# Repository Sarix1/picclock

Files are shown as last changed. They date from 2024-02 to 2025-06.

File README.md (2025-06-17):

# PIC Digital Alarm Clock

A digital alarm clock using a PIC16F690 MCU

Created by [Sari Jokinen](https://github.com/sarix1) in December 2023 - February 2024

## Pictures

<table>
  <tr>
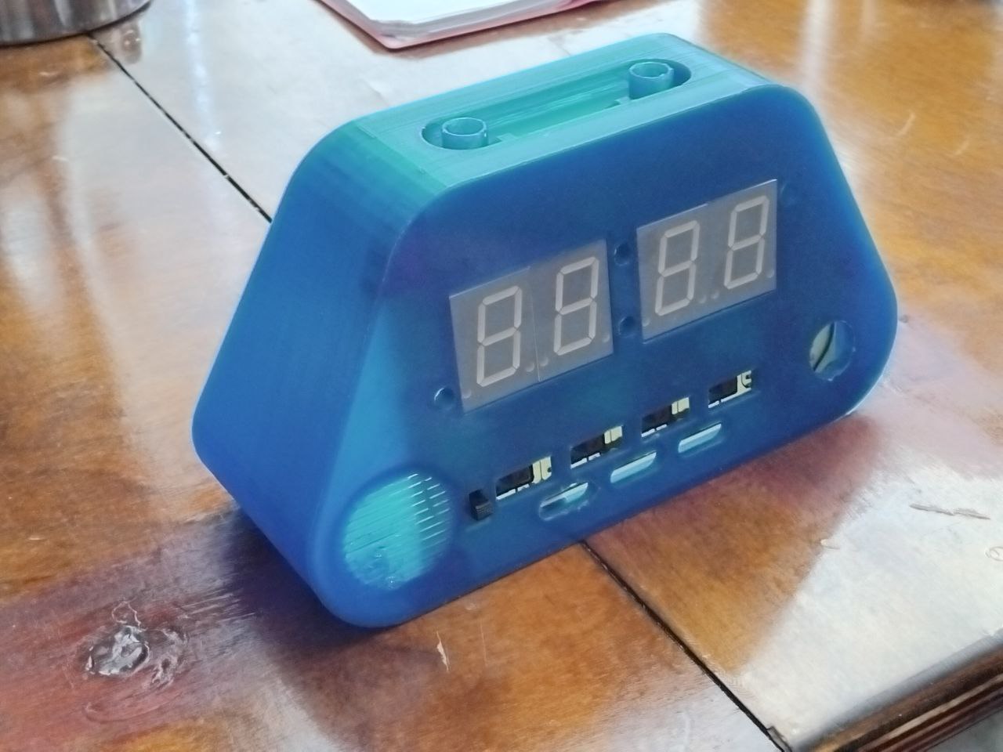
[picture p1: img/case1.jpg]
    <td></td>
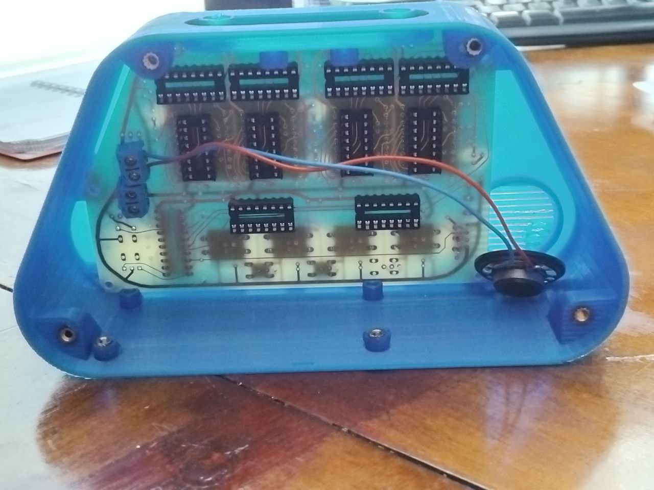
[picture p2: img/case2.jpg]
    <td></td>
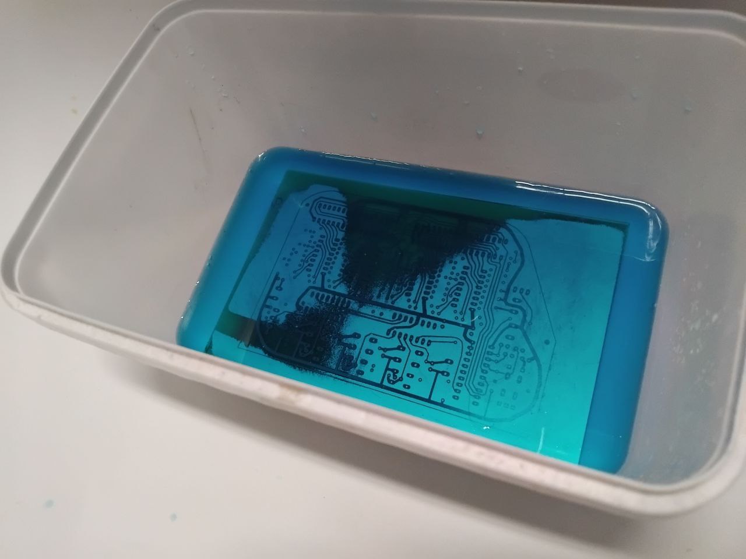
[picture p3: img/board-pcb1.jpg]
    <td></td>
  </tr>
  <tr>
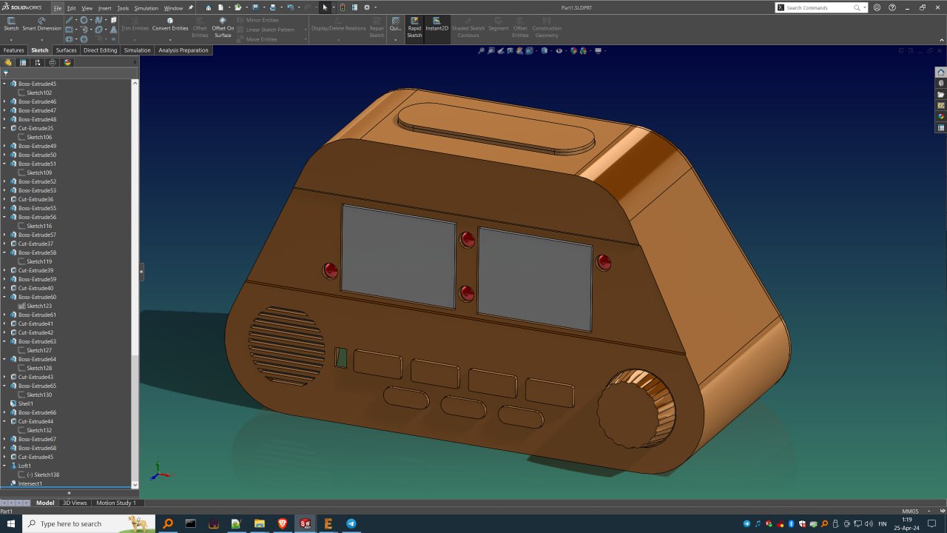
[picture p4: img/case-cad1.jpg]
    <td></td>
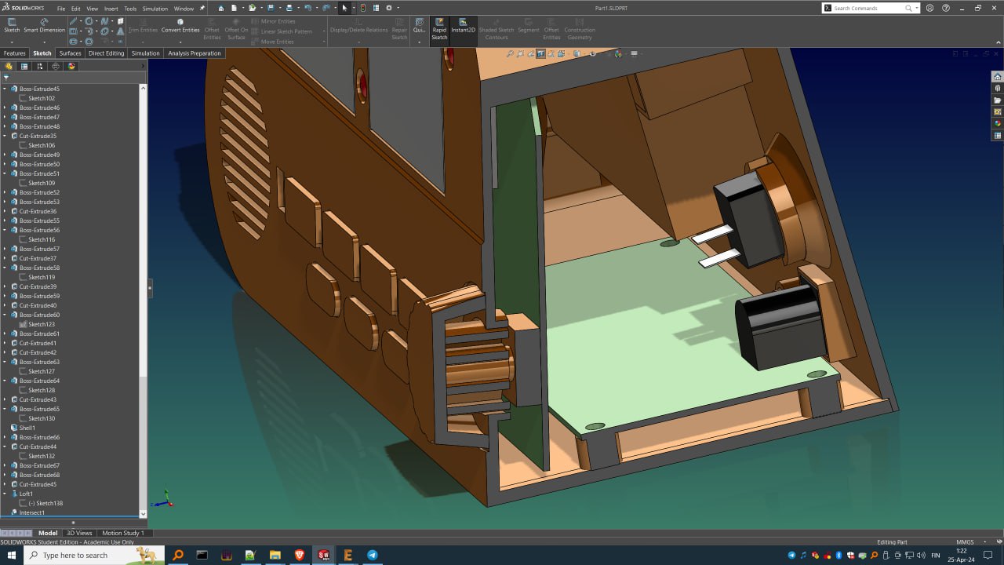
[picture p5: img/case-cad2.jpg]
    <td></td>
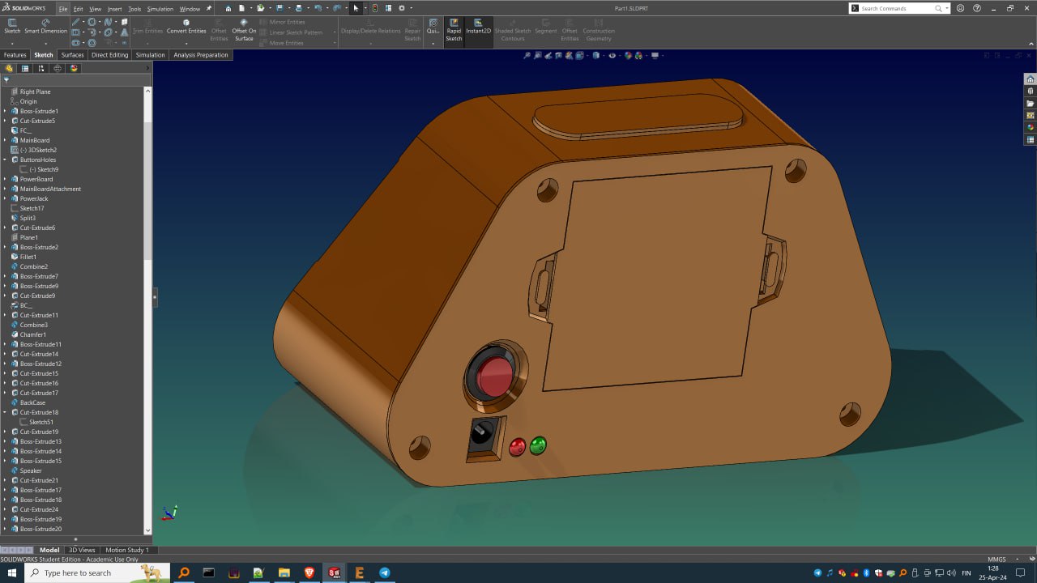
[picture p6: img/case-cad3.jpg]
    <td></td>
  </tr>
  <tr>
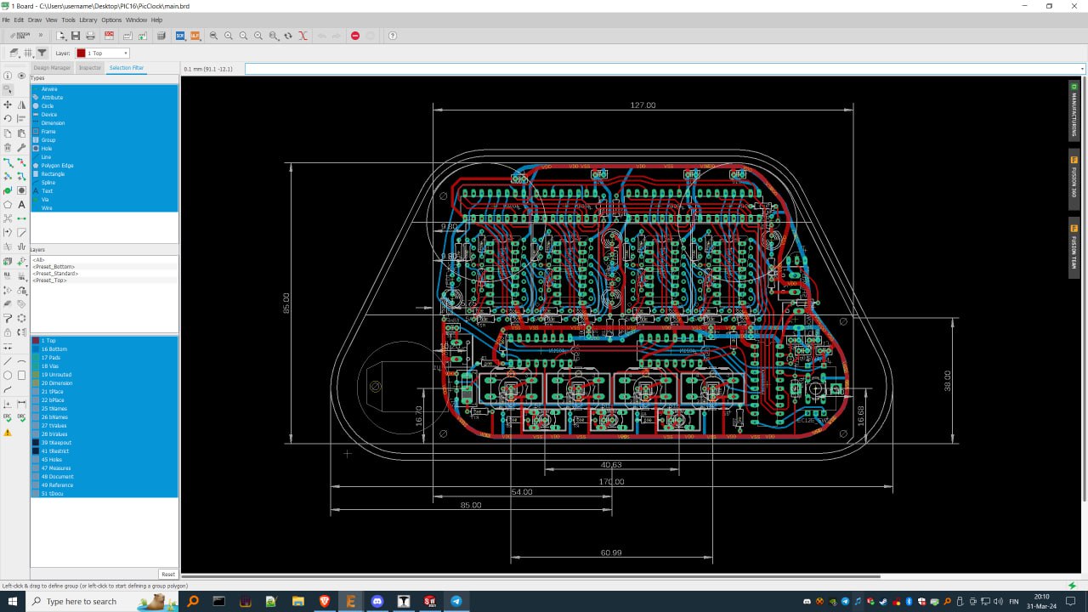
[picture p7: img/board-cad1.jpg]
    <td></td>
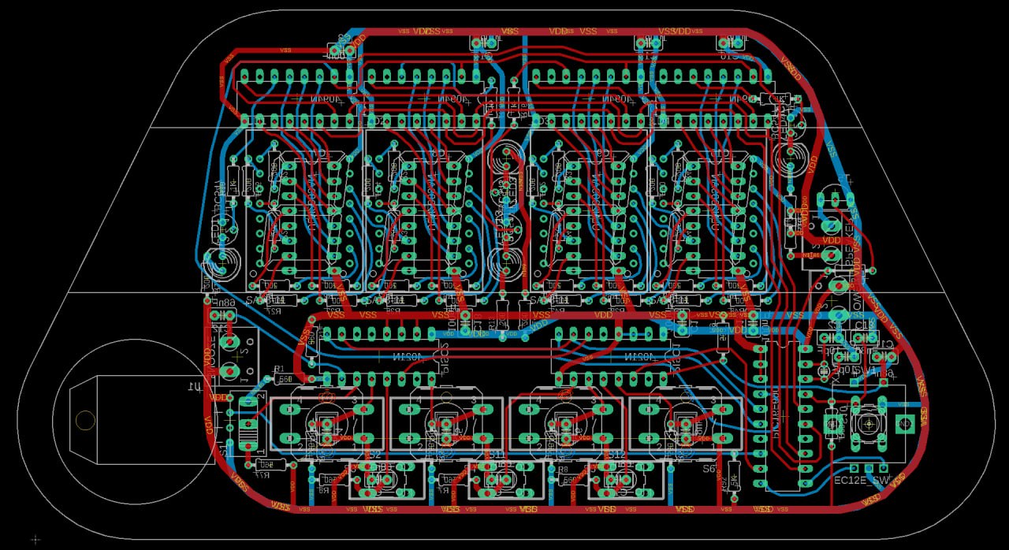
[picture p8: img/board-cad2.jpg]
    <td></td>
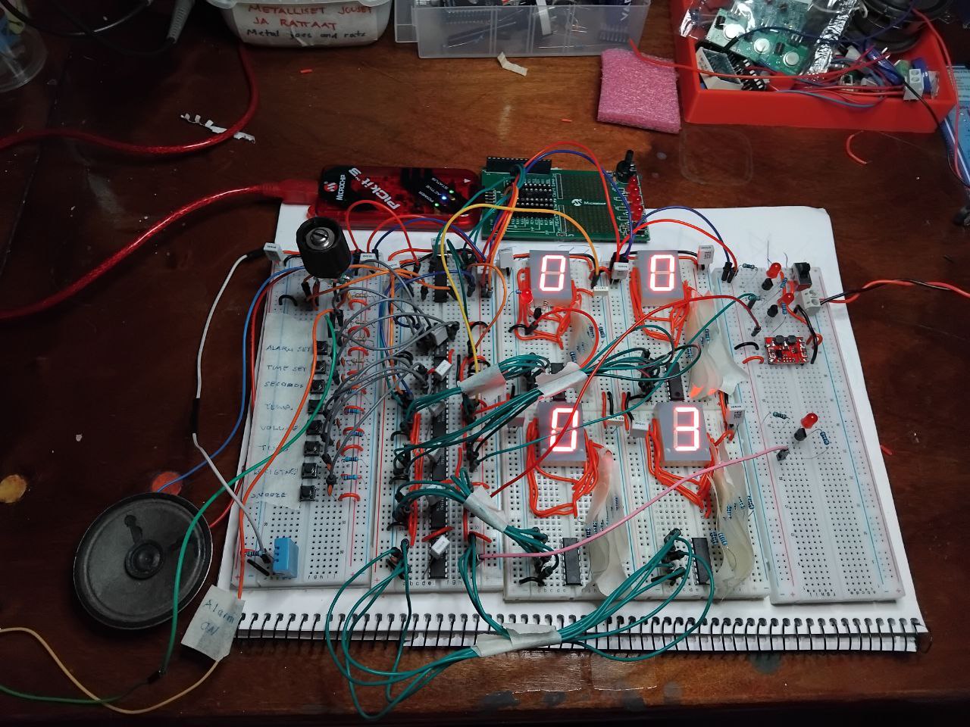
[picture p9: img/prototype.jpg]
    <td></td>
  </tr>
  <tr>
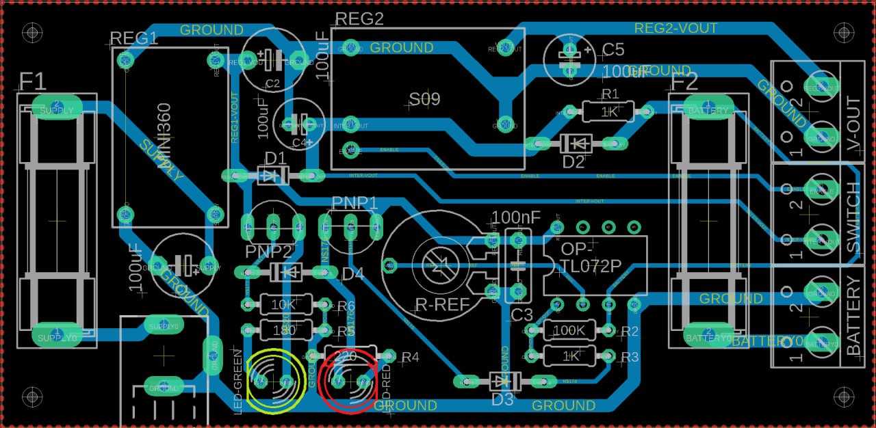
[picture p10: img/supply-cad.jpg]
    <td></td>
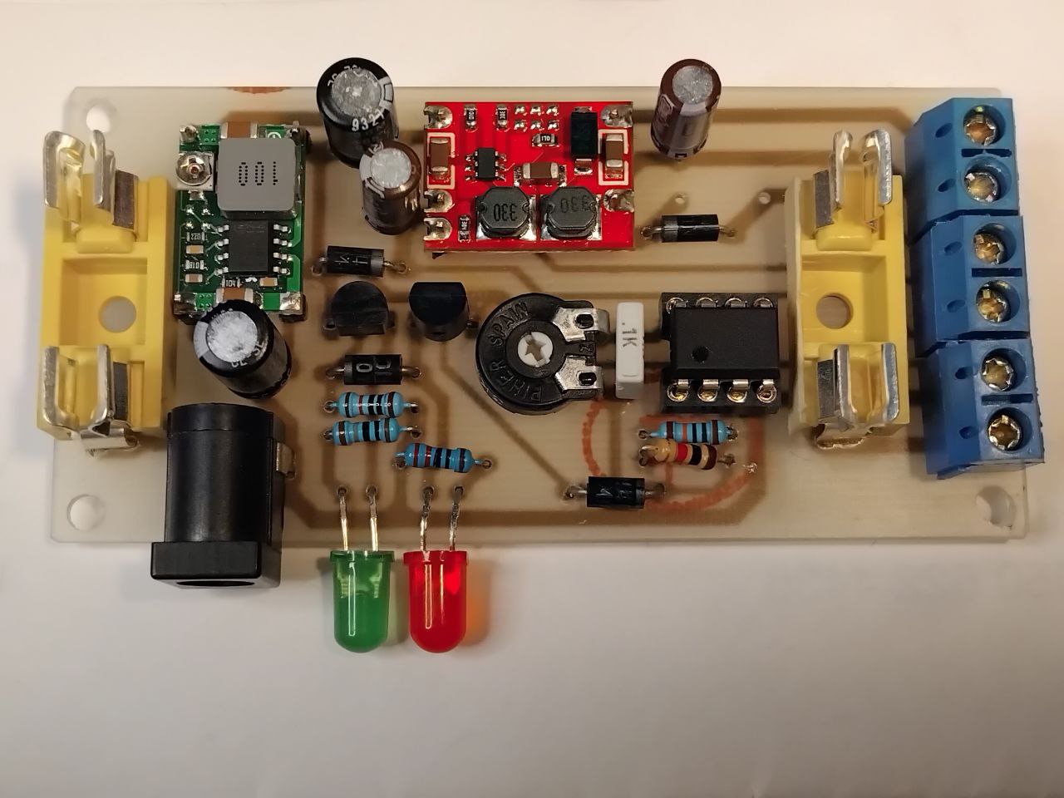
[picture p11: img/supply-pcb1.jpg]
    <td></td>
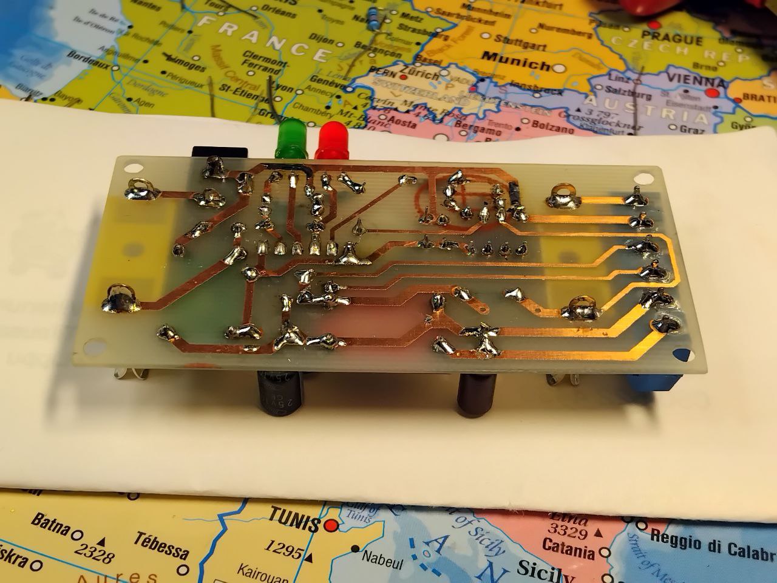
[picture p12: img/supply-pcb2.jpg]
    <td></td>
  </tr>
</table>

## Components

- PIC16F690 (20-pin, 8-bit MCU)
- 4 x 7-segment LED displays
- 10 x push-buttons
- Rotary encoder with push button
- DHT11 temperature/humidity sensor
- PWM-driven speaker on RC5/P1A
- 4 x SIPO shift registers (CD4094B) for display output
- 2 x PISO shift registers (CD4021B) for button input

## Pinout

### PIC16F690

```
                        _______     _______
                       |       \___/       |
                 +5V --|1 VDD        VSS 20|-- 0V
                       |                   |
              Xtal A ->|2 RA5        RA0 19|-- Unused
                       |   osc1            |
              Xtal B ->|3 RA4        RA1 18|-- Unused
                       |   osc2            |
               Reset ->|4 RA3        RA2 17|-> SIPO Output Enable
                       |   mclr       in   |
PWM / Speaker Signal <~|5 RC5        RC0 16|-> PISO Clock
                       |   p1a        out  |
          SIPO Latch <-|6 RC4        RC1 15|-> PISO Latch
                       |   out        out  |
              Unused --|7 RC3        RC2 14|-- Unused
                       |   p1c        p1d  |
           SIPO Data <-|8 RC6        RB4 13|<-> DHT11
                       |   out        an10 |
          SIPO Clock <-|9 RC7        RB5 12|<- PISO Data
                       |   out        in   |
      Rot. Encoder B ->|10 RB7       RB6 11|<- Rot. Encoder A
                       |    in        in   |
                       '-------------------'
                             PIC16F690
```

### Rotary Encoder
```
       ______    
  A <-|  __  |-> Button: Min/Hour
Gnd --| (__) |
  B <-|______|-- Gnd
```

### Parallel-In, Serial-Out Shift Registers
```
                     ____   ____
     Button Input ->|PI8 \_/ VDD|-- +5V
           Unused <-|Q6      PI7|<- Unused 
        PISO Data <-|Q8      PI6|<- BTN_SENSOR
     BTN_TIME_SET ->|PI4     PI5|<- BTN_SEC_SET
    BTN_ALARM_SET ->|PI3      Q7|-> Unused
      BTN_ENCODER ->|PI2     SER|<- CD4021B 2 Q8 <-.
TN_ALARM_TIMER_ON ->|PI1     CLK|<- PISO Clock     |
               0V --|VSS     LAT|<- PISO Latch     |
                    '-----------'                  |
                      CD4021B 1                    |
.--------------------------------------------------'
|                    ____   ____
|          Unused ->|PI8 \_/ VDD|-- +5V
|          Unused <-|Q6      PI7|<- Unused
'-- CD4021B 1 SER <-|Q8      PI6|<- Unused
       BTN_SNOOZE ->|PI4     PI5|<- Unused
   BTN_BRIGHT_SET ->|PI3      Q7|-> Unused
     BTN_TUNE_SET ->|PI2     SER|-> Unused
   BTN_VOLUME_SET ->|PI1     CLK|<- PISO Clock
               0V --|VSS     LAT|<- PISO Latch
                    '-----------'
                      CD4021B 2
```

### Serial-In, Parallel-Out Shift Registers
```
                     ____   ____
       SIPO Latch ->|LAT \_/ VDD|-- +5V
        SIPO Data ->|DAT      OE|<- LED Enable
       SIPO Clock ->|CLK      Q5|-> 7-Seg 1 E
        7-Seg 1 A <-|Q1       Q6|-> 7-Seg 1 F
        7-Seg 1 B <-|Q2       Q7|-> 7-Seg 1 G
        7-Seg 1 C <-|Q3       Q8|-> Unused
        7-Seg 1 D <-|Q4      Q'S|-> Unused
               0V --|VSS      QS|-> CD4094 2 DAT --.
                    '-----------'                  |
                      CD4094B 1                    |
.--------------------------------------------------'
|                    ____   ____
|      SIPO Latch ->|LAT \_/ VDD|-- +5V
'--> CD4094B 1 QS ->|DAT      OE|<- LED Enable
       SIPO Clock ->|CLK      Q5|-> 7-Seg 2 E
        7-Seg 2 A <-|Q1       Q6|-> 7-Seg 2 F
        7-Seg 2 B <-|Q2       Q7|-> 7-Seg 2 G
        7-Seg 2 C <-|Q3       Q8|-> Unused
        7-Seg 2 D <-|Q4      Q'S|-> Unused
               0V --|VSS      QS|-> CD4094 3 DAT --.
                    '-----------'                  |
                      CD4094B 2                    |
.--------------------------------------------------'
|                    ____   ____
|      SIPO Latch ->|LAT \_/ VDD|-- +5V
'--> CD4094B 2 QS ->|DAT      OE|<- LED Enable
       SIPO Clock ->|CLK      Q5|-> 7-Seg 3 E
        7-Seg 3 A <-|Q1       Q6|-> 7-Seg 3 F
        7-Seg 3 B <-|Q2       Q7|-> 7-Seg 3 G
        7-Seg 3 C <-|Q3       Q8|-> Unused
        7-Seg 3 D <-|Q4      Q'S|-> Unused
               0V --|VSS      QS|-> CD4094 4 DAT --.
                    '-----------'                  |
                      CD4094B 3                    |
.--------------------------------------------------'
|                    ____   ____
|      SIPO Latch ->|LAT \_/ VDD|-- +5V
'--> CD4094B 3 QS ->|DAT      OE|<- LED Enable
       SIPO Clock ->|CLK      Q5|-> 7-Seg 4 E
        7-Seg 4 A <-|Q1       Q6|-> 7-Seg 4 F
        7-Seg 4 B <-|Q2       Q7|-> 7-Seg 4 G
        7-Seg 4 C <-|Q3       Q8|-> Unused
        7-Seg 4 D <-|Q4      Q'S|-> Unused
               0V --|VSS      QS|-> Unused
                    '-----------'                  
                      CD4094B 4
```

## Hardware Layout Overview

```mermaid
graph TD
    subgraph "Buttons"
        BTN[10 Push Buttons]
    end
    
    subgraph "Direct Inputs"
        ENC[Rotary Encoder]
        DHT[DHT11 Sensor]
    end
    
    subgraph "Button Interface"
        PISO2[CD4021B #2]
        PISO1[CD4021B #1]
    end
    
    subgraph "Core"
        PIC[PIC16F690]
    end
    
    subgraph "Display Interface"
        SIPO1[CD4094B #1]
        SIPO2[CD4094B #2]
        SIPO3[CD4094B #3]
        SIPO4[CD4094B #4]
    end
    
    subgraph "Outputs"
        SEG[4x 7-Segment]
        SPK[Speaker]
    end
    
    BTN --> PISO2
    BTN --> PISO1
    PISO2 -->|Serial| PISO1
    PISO1 -->|Pin 12| PIC
    
    ENC -->|Pins 10,11| PIC
    DHT <-->|Pin 13| PIC
    
    PIC -->|Pin 8| SIPO1
    SIPO1 --> SIPO2
    SIPO2 --> SIPO3
    SIPO3 --> SIPO4
    
    SIPO1 --> SEG
    SIPO2 --> SEG
    SIPO3 --> SEG
    SIPO4 --> SEG
    
    PIC -->|Pin 5| SPK
```

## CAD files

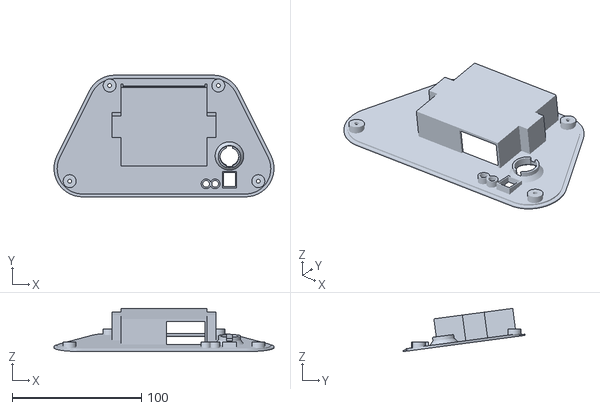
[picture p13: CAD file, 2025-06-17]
case/BackCase_v2.STL
170.0 x 94.0 x 33.4

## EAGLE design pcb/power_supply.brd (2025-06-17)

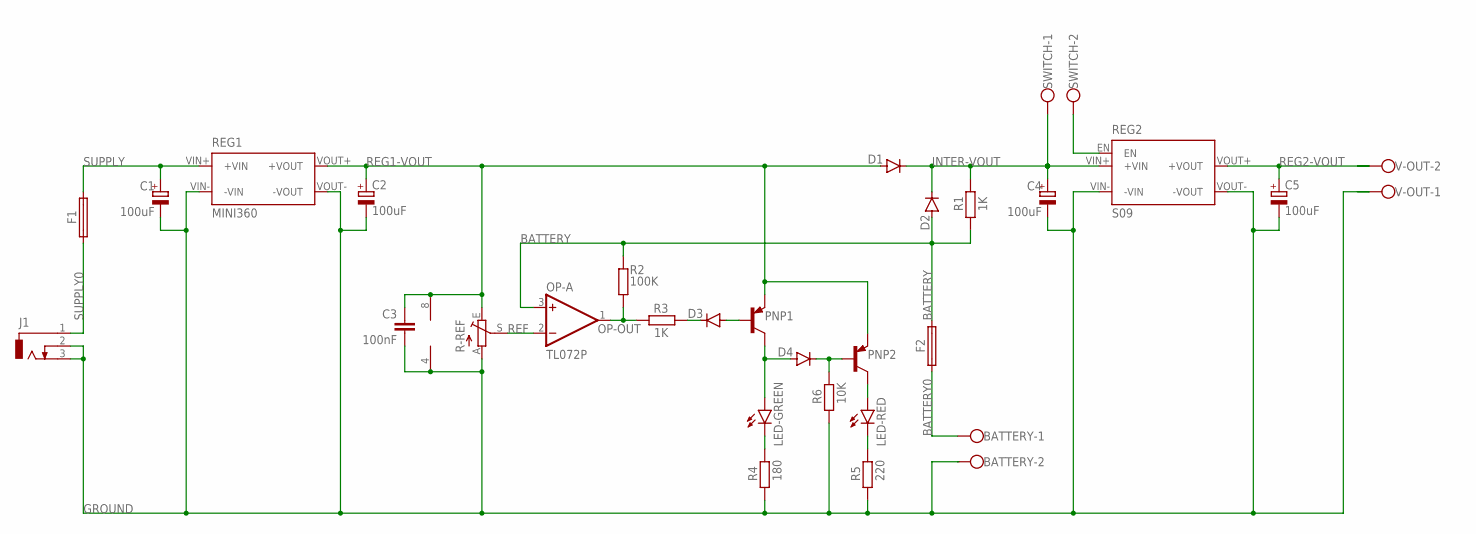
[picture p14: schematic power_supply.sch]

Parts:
BATTERY: W237-102
C1, C2: 100uF; E5-6
C3: 100nF; C5B2.5
C4, C5: 100uF; E2-5
D1, D2, D3, D4: BAS15; DO34-7
F1, F2: SH22,5
J1: DCJ0303
LED-GREEN: LED5MM
LED-RED: LED5MM
OP-: TL072P; DIL08
PNP1, PNP2: BC557A-PNP-TO92-EBC; TO92-EBC
R1, R3: 1K; 0204/7
R2: 100K; 0204/7
R4: 180; 0204/7
R5: 220; 0204/7
R6: 10K; 0204/7
R-REF: TRIM_EU-PT10; PT-10
REG1: MINI360; DC-DC-CONVERTER-MINI360
REG2: S09; DC-DC-CONVERTER-S09
SWITCH: W237-102
V-OUT: W237-102

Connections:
BATTERY: D2.A, F2.1, OP-.3 (+IN), R1.1, R2.2
BATTERY0: BATTERY.1, F2.2
ENABLE: REG2.EN, SWITCH.2
GROUND: BATTERY.2, C1.-, C2.-, C3.2, C4.-, C5.-, J1.2, J1.3, OP-.4 (V-), R4.1, R5.1, R6.1, R-REF.A, REG1.VIN- (-VIN), REG1.VOUT- (-VOUT), REG2.VIN- (-VIN), REG2.VOUT- (-VOUT), V-OUT.1
INTER-VOUT: C4.+, D1.C, D2.C, R1.2, REG2.VIN+ (+VIN), SWITCH.1
unnamed: LED-RED.A, PNP2.C
unnamed: D3.C, R3.1
unnamed: D3.A, PNP1.B
unnamed: D4.A, LED-GREEN.A, PNP1.C
unnamed: D4.C, PNP2.B, R6.2
unnamed: LED-RED.K (C), R5.2
unnamed: LED-GREEN.K (C), R4.2
OP-OUT: OP-.1 (OUT), R2.1, R3.2
REF: OP-.2 (-IN), R-REF.S
REG1-VOUT: C2.+, C3.1, D1.A, OP-.8 (V+), PNP1.E, PNP2.E, R-REF.E, REG1.VOUT+ (+VOUT)
REG2-VOUT: C5.+, REG2.VOUT+ (+VOUT), V-OUT.2
SUPPLY: C1.+, F1.2, REG1.VIN+ (+VIN)
SUPPLY0: F1.1, J1.1

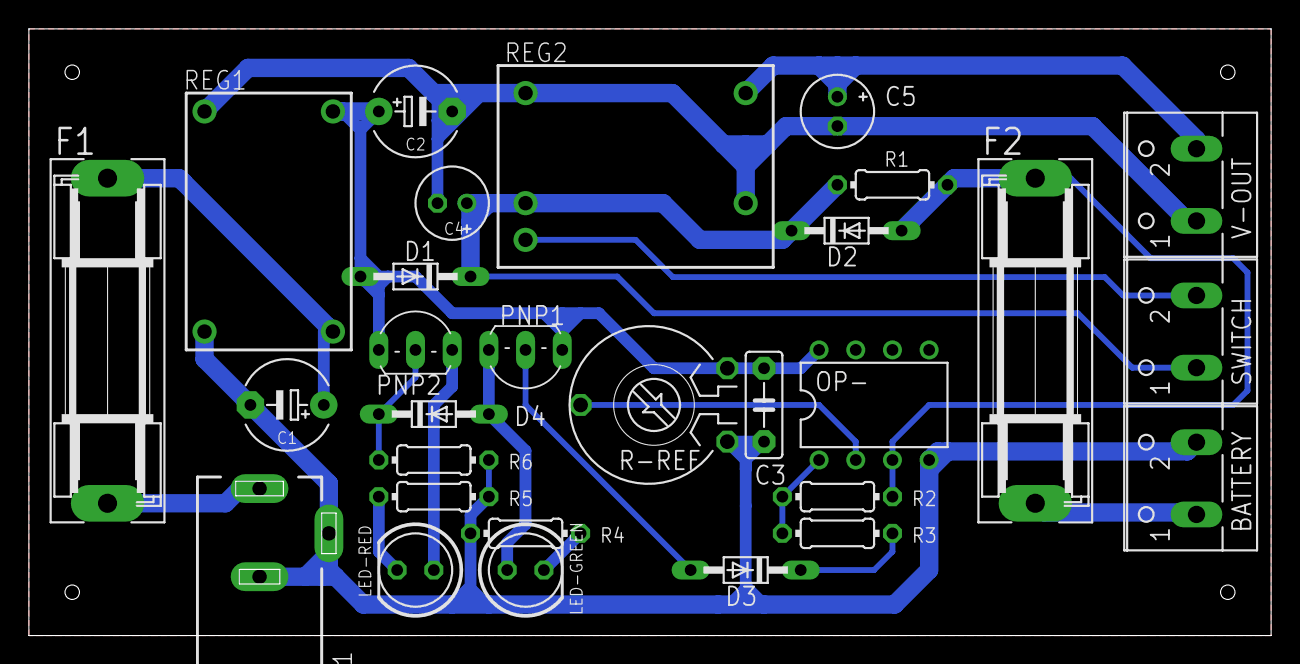
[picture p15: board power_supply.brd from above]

Board: 2 copper layers, 86.0 x 42.0 mm, 29 parts (0 on the bottom side), 18 nets.

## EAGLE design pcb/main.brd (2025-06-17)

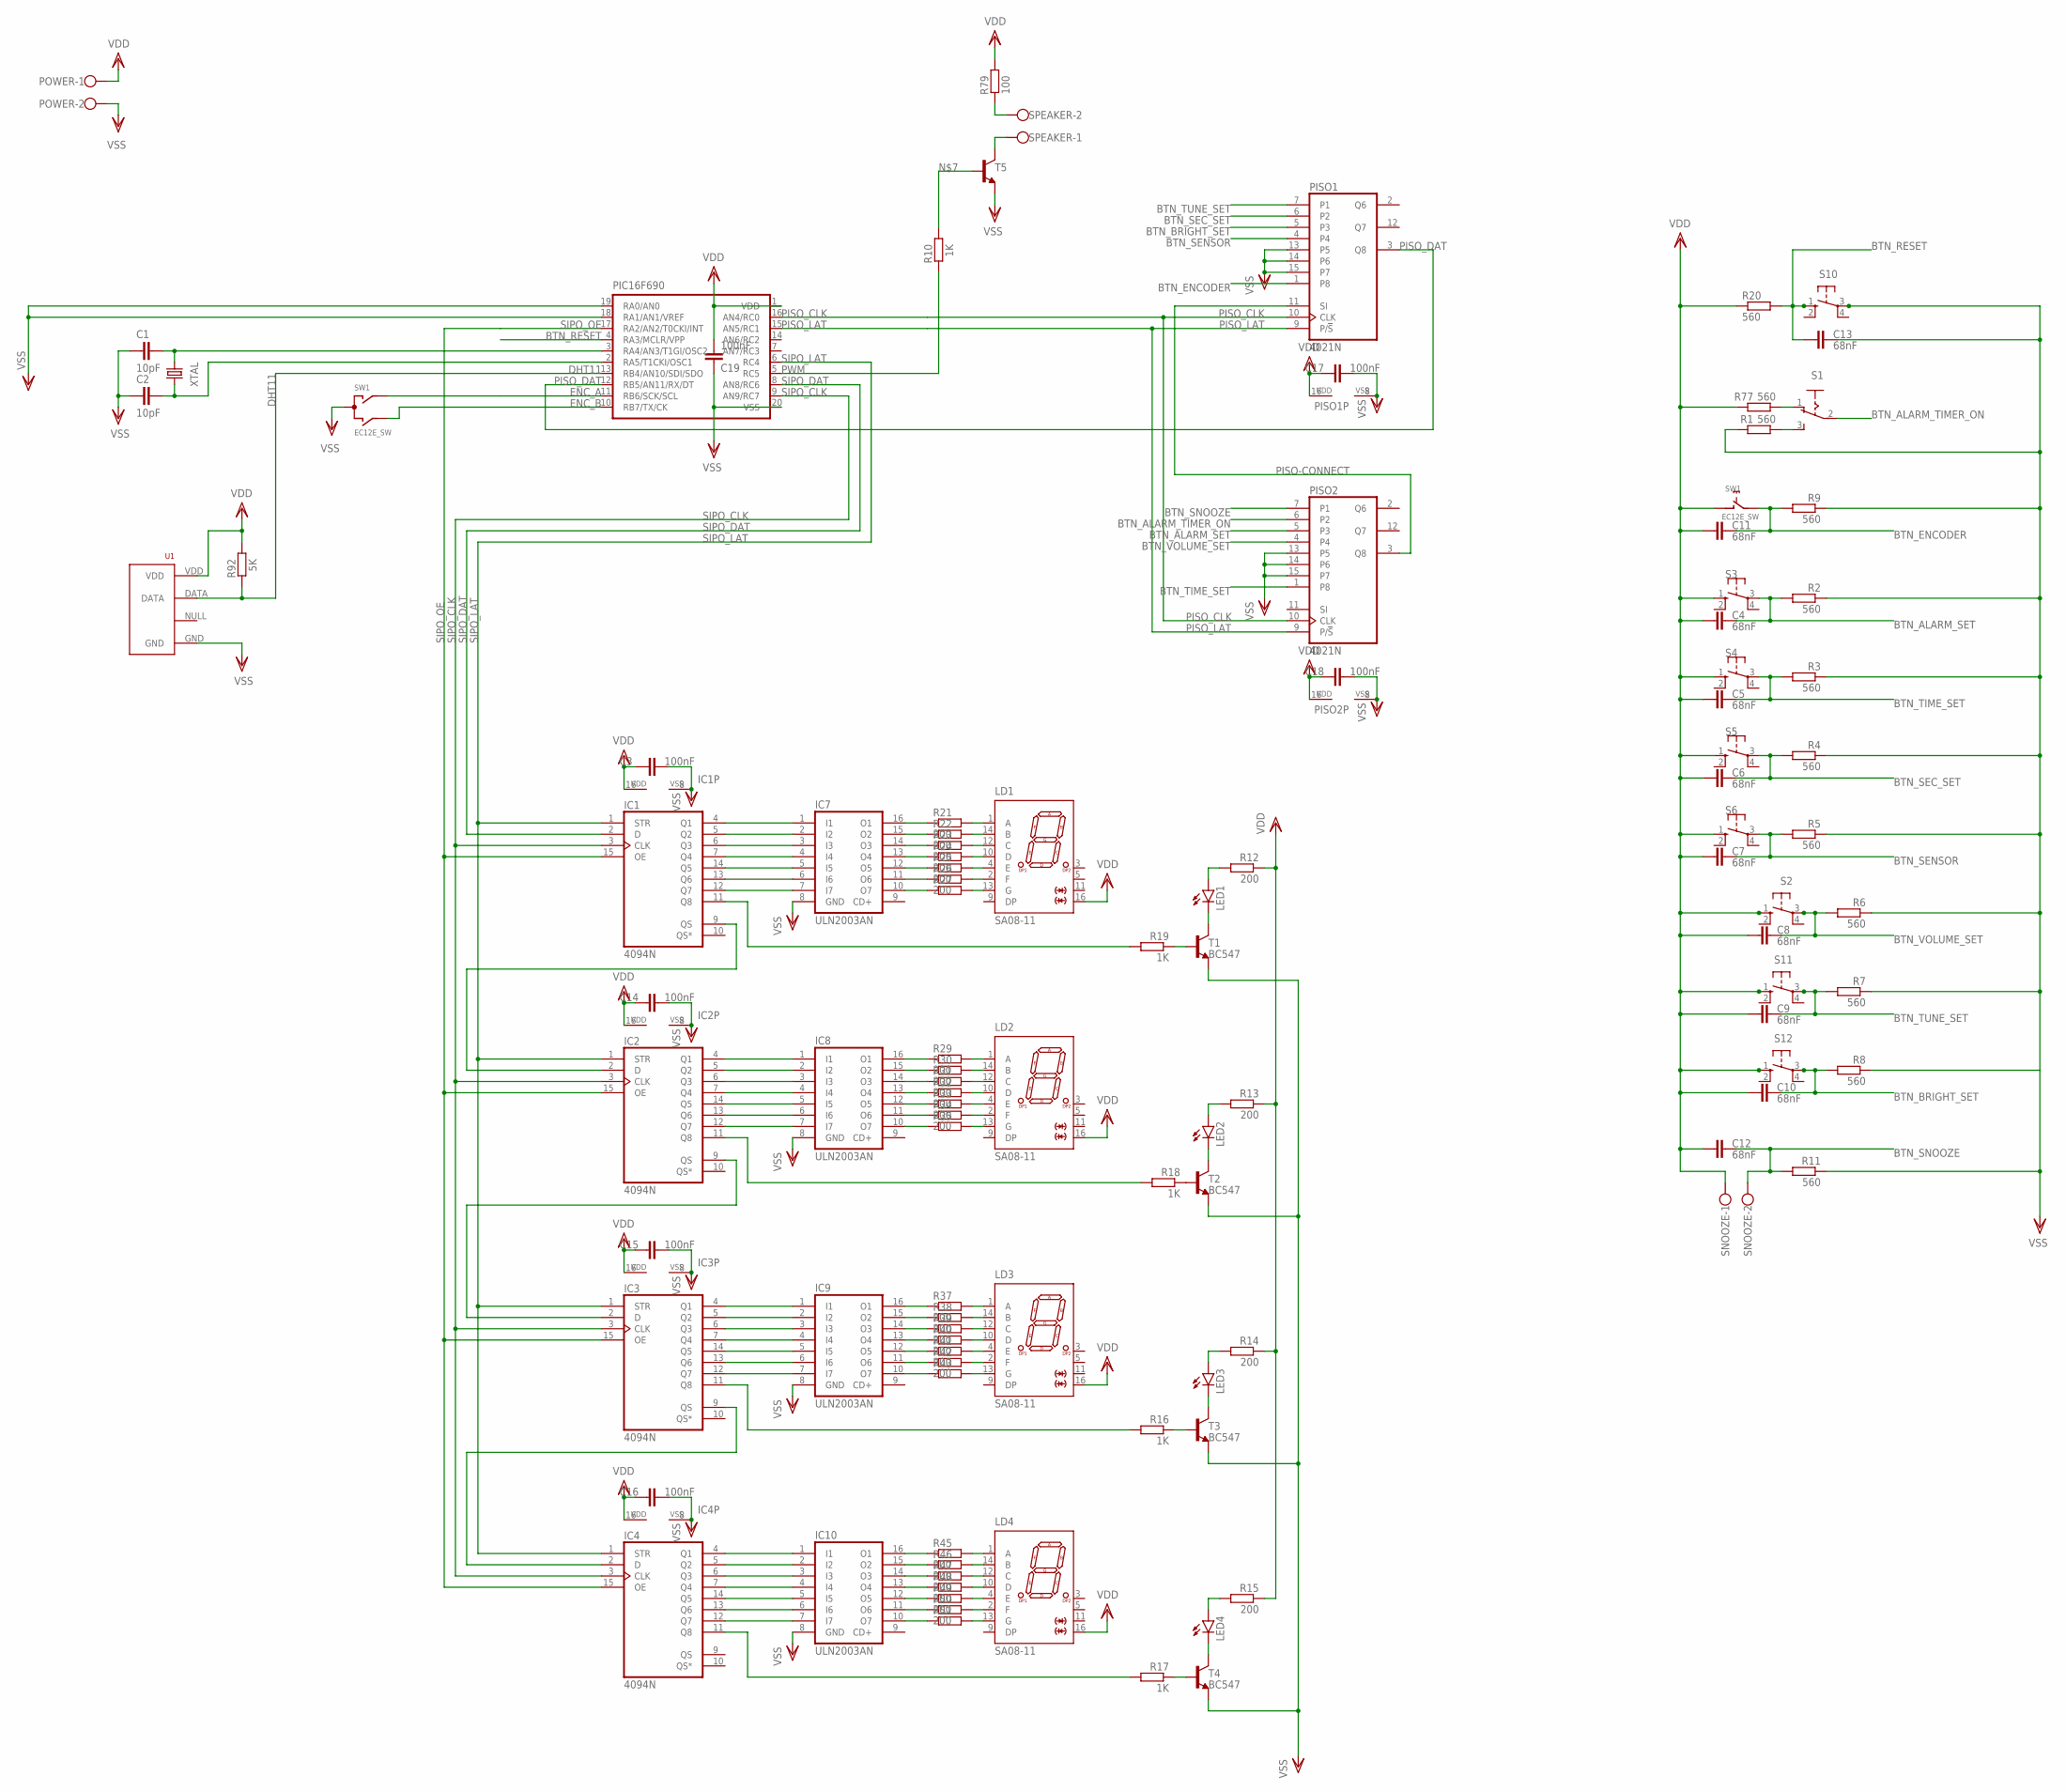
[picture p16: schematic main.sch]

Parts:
C1, C2: 10pF; C2.5-2
C3, C14, C15, C16, C17, C18, C19: 100nF; C2.5-2
C4, C5, C6, C7, C8, C9, C10, C11, C12, C13: 68nF; C2.5-2
IC1, IC2, IC3, IC4: 4094N; DIL16
IC7, IC8, IC9, IC10: ULN2003AN; DIL16
LD1, LD2, LD3, LD4: SA08-11; SA08
LED1, LED2, LED3, LED4: LED5MM
PIC16F690: PIC16F6XX; DIL20
PISO1, PISO2: 4021N; DIL16
POWER: W237-102
R1, R2, R3, R4, R5, R6, R7, R8, R9, R11, R20, R77: 560; 0204/7
R10, R16, R17, R18, R19: 1K; 0204/7
R12, R13, R14, R15, R21, R22, R23, R24, R25, R26, R27, R29, R30, R31, R32, R33, R34, R35, R37, R38, R39, R40, R41, R42, R43, R45, R46, R47, R48, R49, R50, R51: 200; 0204/7
R79: 100; 0204/7
R92: 5K; 0204/7
S1: 255SB
S2, S10, S11, S12: 10-XX; B3F-10XX
S3, S4, S5, S6: 40-XX; B3F-40XX
SNOOZE: W237-102
SPEAKER: W237-102
SW1: EC12E_SW; ALPS_EC12E_SW
T1, T2, T3, T4: BC547; TO92
T5: 2N2222-NPN-TO92-EBC; TO92-EBC
U1: RHT03_DHT-22_AM2302RA; RHT03_DHT-22/RA
XTAL: CRYSTALTC26V; TC26V

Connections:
BTN_ALARM_SET: C4.2, PISO2.5 (P3), R2.2, S3.3
BTN_ALARM_TIMER_ON: PISO2.6 (P2), S1.2
BTN_BRIGHT_SET: C10.2, PISO1.5 (P3), R8.2, S12.3
BTN_ENCODER: C11.2, PISO1.1 (P8), R9.2, SW1.E (2)
BTN_RESET: C13.1, PIC16F690.4 (RA3/MCLR/VPP), R20.2, S10.1 (S)
BTN_SEC_SET: C6.2, PISO1.6 (P2), R4.2, S5.3
BTN_SENSOR: C7.2, PISO1.4, R5.2, S6.3
BTN_SNOOZE: C12.2, PISO2.7 (P1), R11.2, SNOOZE.2
BTN_TIME_SET: C5.2, PISO2.1 (P8), R3.2, S4.3
BTN_TUNE_SET: C9.2, PISO1.7 (P1), R7.2, S11.3
BTN_VOLUME_SET: C8.2, PISO2.4, R6.2, S2.3
DHT11: PIC16F690.13 (RB4/AN10/SDI/SDO), R92.2, U1.DATA
ENC_A: PIC16F690.11 (RB6/SCK/SCL), SW1.A
ENC_B: PIC16F690.10 (RB7/TX/CK), SW1.B
unnamed: C1.2, PIC16F690.3 (RA4/AN3/T1GI/OSC2), XTAL.1
unnamed: C2.2, PIC16F690.2 (RA5/T1CKI/OSC1), XTAL.2
unnamed: IC7.16 (O1), R21.1
unnamed: IC7.15 (O2), R22.1
unnamed: IC7.14 (O3), R23.1
unnamed: R10.1, T5.B
unnamed: R18.1, T2.2 (B)
unnamed: IC3.4 (Q1), IC9.1 (I1)
unnamed: IC3.5 (Q2), IC9.2 (I2)
unnamed: IC3.6 (Q3), IC9.3 (I3)
unnamed: IC3.7 (Q4), IC9.4 (I4)
unnamed: IC3.14 (Q5), IC9.5 (I5)
unnamed: IC3.13 (Q6), IC9.6 (I6)
unnamed: IC3.12 (Q7), IC9.7 (I7)
unnamed: IC1.11 (Q8), R19.2
unnamed: IC2.4 (Q1), IC8.1 (I1)
unnamed: IC2.5 (Q2), IC8.2 (I2)
unnamed: IC7.13 (O4), R24.1
unnamed: IC7.12 (O5), R25.1
unnamed: IC7.11 (O6), R26.1
unnamed: IC2.6 (Q3), IC8.3 (I3)
unnamed: IC2.7 (Q4), IC8.4 (I4)
unnamed: IC2.14 (Q5), IC8.5 (I5)
unnamed: IC2.13 (Q6), IC8.6 (I6)
unnamed: IC2.12 (Q7), IC8.7 (I7)
unnamed: IC2.11 (Q8), R18.2
unnamed: IC1.4 (Q1), IC7.1 (I1)
unnamed: IC1.5 (Q2), IC7.2 (I2)
unnamed: IC1.6 (Q3), IC7.3 (I3)
unnamed: IC1.7 (Q4), IC7.4 (I4)
unnamed: IC1.14 (Q5), IC7.5 (I5)
unnamed: IC1.13 (Q6), IC7.6 (I6)
unnamed: IC1.12 (Q7), IC7.7 (I7)
unnamed: IC3.11 (Q8), R16.2
unnamed: IC4.4 (Q1), IC10.1 (I1)
unnamed: IC4.5 (Q2), IC10.2 (I2)
unnamed: IC4.6 (Q3), IC10.3 (I3)
unnamed: IC4.7 (Q4), IC10.4 (I4)
unnamed: IC4.14 (Q5), IC10.5 (I5)
unnamed: IC4.13 (Q6), IC10.6 (I6)
unnamed: IC4.12 (Q7), IC10.7 (I7)
unnamed: IC4.11 (Q8), R17.2
unnamed: LD1.1 (A), R21.2
unnamed: LD1.14 (B), R22.2
unnamed: LD1.12 (C), R23.2
unnamed: LD1.10 (D), R24.2
unnamed: LD1.4 (E), R25.2
unnamed: LD1.2 (F), R26.2
unnamed: LD1.13 (G), R27.2
unnamed: LD2.1 (A), R29.2
unnamed: LD2.14 (B), R30.2
unnamed: LD2.12 (C), R31.2
unnamed: LD2.10 (D), R32.2
unnamed: LD2.4 (E), R33.2
unnamed: LD2.2 (F), R34.2
unnamed: LD2.13 (G), R35.2
unnamed: LD3.1 (A), R37.2
unnamed: LD3.14 (B), R38.2
unnamed: LD3.12 (C), R39.2
unnamed: LD3.10 (D), R40.2
unnamed: LD3.4 (E), R41.2
unnamed: LD3.2 (F), R42.2
unnamed: LD3.13 (G), R43.2
unnamed: LD4.1 (A), R45.2
unnamed: LD4.14 (B), R46.2
unnamed: LD4.12 (C), R47.2
unnamed: LD4.10 (D), R48.2
unnamed: LD4.4 (E), R49.2
unnamed: LD4.2 (F), R50.2
unnamed: LD4.13 (G), R51.2
unnamed: LED1.K (C), T1.3 (C)
unnamed: LED2.K (C), T2.3 (C)
unnamed: LED3.K (C), T3.3 (C)
unnamed: LED4.K (C), T4.3 (C)
unnamed: R19.1, T1.2 (B)
unnamed: R16.1, T3.2 (B)
unnamed: R17.1, T4.2 (B)
unnamed: LED4.A, R15.2
unnamed: LED3.A, R14.2
unnamed: LED2.A, R13.2
unnamed: LED1.A, R12.2
unnamed: IC7.10 (O7), R27.1
unnamed: IC1.9 (QS), IC2.2 (D)
unnamed: IC2.9 (QS), IC3.2 (D)
unnamed: IC3.9 (QS), IC4.2 (D)
unnamed: IC8.16 (O1), R29.1
unnamed: IC8.15 (O2), R30.1
unnamed: IC8.14 (O3), R31.1
unnamed: IC8.13 (O4), R32.1
unnamed: IC8.12 (O5), R33.1
unnamed: IC8.11 (O6), R34.1
unnamed: IC8.10 (O7), R35.1
unnamed: IC9.16 (O1), R37.1
unnamed: IC9.15 (O2), R38.1
unnamed: IC9.14 (O3), R39.1
unnamed: IC9.13 (O4), R40.1
unnamed: IC9.12 (O5), R41.1
unnamed: IC9.11 (O6), R42.1
unnamed: IC9.10 (O7), R43.1
unnamed: IC10.16 (O1), R45.1
unnamed: IC10.15 (O2), R46.1
unnamed: IC10.14 (O3), R47.1
unnamed: IC10.13 (O4), R48.1
unnamed: IC10.12 (O5), R49.1
unnamed: IC10.11 (O6), R50.1
unnamed: IC10.10 (O7), R51.1
unnamed: R77.1, S1.1 (O)
unnamed: R1.1, S1.3 (S)
unnamed: R79.2, SPEAKER.2
unnamed: SPEAKER.1, T5.C
PISO-CONNECT: PISO1.11 (SI), PISO2.3 (Q8)
PISO_CLK: PIC16F690.16 (AN4/RC0), PISO1.10 (CLK), PISO2.10 (CLK)
PISO_DAT: PIC16F690.12 (RB5/AN11/RX/DT), PISO1.3 (Q8)
PISO_LAT: PIC16F690.15 (AN5/RC1), PISO1.9 (P/!S), PISO2.9 (P/!S)
PWM: PIC16F690.5 (RC5), R10.2
SIPO_CLK: IC1.3 (CLK), IC2.3 (CLK), IC3.3 (CLK), IC4.3 (CLK), PIC16F690.9 (AN9/RC7)
SIPO_DAT: IC1.2 (D), PIC16F690.8 (AN8/RC6)
SIPO_LAT: IC1.1 (STR), IC2.1 (STR), IC3.1 (STR), IC4.1 (STR), PIC16F690.6 (RC4)
SIPO_OE: IC1.15 (OE), IC2.15 (OE), IC3.15 (OE), IC4.15 (OE), PIC16F690.17 (RA2/AN2/T0CKI/INT)
VDD: C3.1, C4.1, C5.1, C6.1, C7.1, C8.1, C9.1, C10.1, C11.1, C12.1, C14.1, C15.1, C16.1, C17.1, C18.1, C19.2, IC1.16 (VDD), IC2.16 (VDD), IC3.16 (VDD), IC4.16 (VDD), LD1.16 (AK), LD2.16 (AK), LD3.16 (AK), LD4.16 (AK), PIC16F690.1 (VDD), PISO1.16 (VDD), PISO2.16 (VDD), POWER.1, R12.1, R13.1, R14.1, R15.1, R20.1, R77.2, R79.1, R92.1, S2.1 (S), S3.1 (S), S4.1 (S), S5.1 (S), S6.1 (S), S11.1 (S), S12.1 (S), SNOOZE.1, SW1.D (1), U1.VDD
VSS: C1.1, C2.1, C3.2, C13.2, C14.2, C15.2, C16.2, C17.2, C18.2, C19.1, IC1.8 (VSS), IC2.8 (VSS), IC3.8 (VSS), IC4.8 (VSS), IC7.8 (GND), IC8.8 (GND), IC9.8 (GND), IC10.8 (GND), PIC16F690.18 (RA1/AN1/VREF), PIC16F690.19 (RA0/AN0), PIC16F690.20 (VSS), PISO1.8 (VSS), PISO1.13 (P5), PISO1.14 (P6), PISO1.15 (P7), PISO2.8 (VSS), PISO2.13 (P5), PISO2.14 (P6), PISO2.15 (P7), POWER.2, R1.2, R2.1, R3.1, R4.1, R5.1, R6.1, R7.1, R8.1, R9.1, R11.1, S10.3, SW1.C, T1.1 (E), T2.1 (E), T3.1 (E), T4.1 (E), T5.E, U1.GND

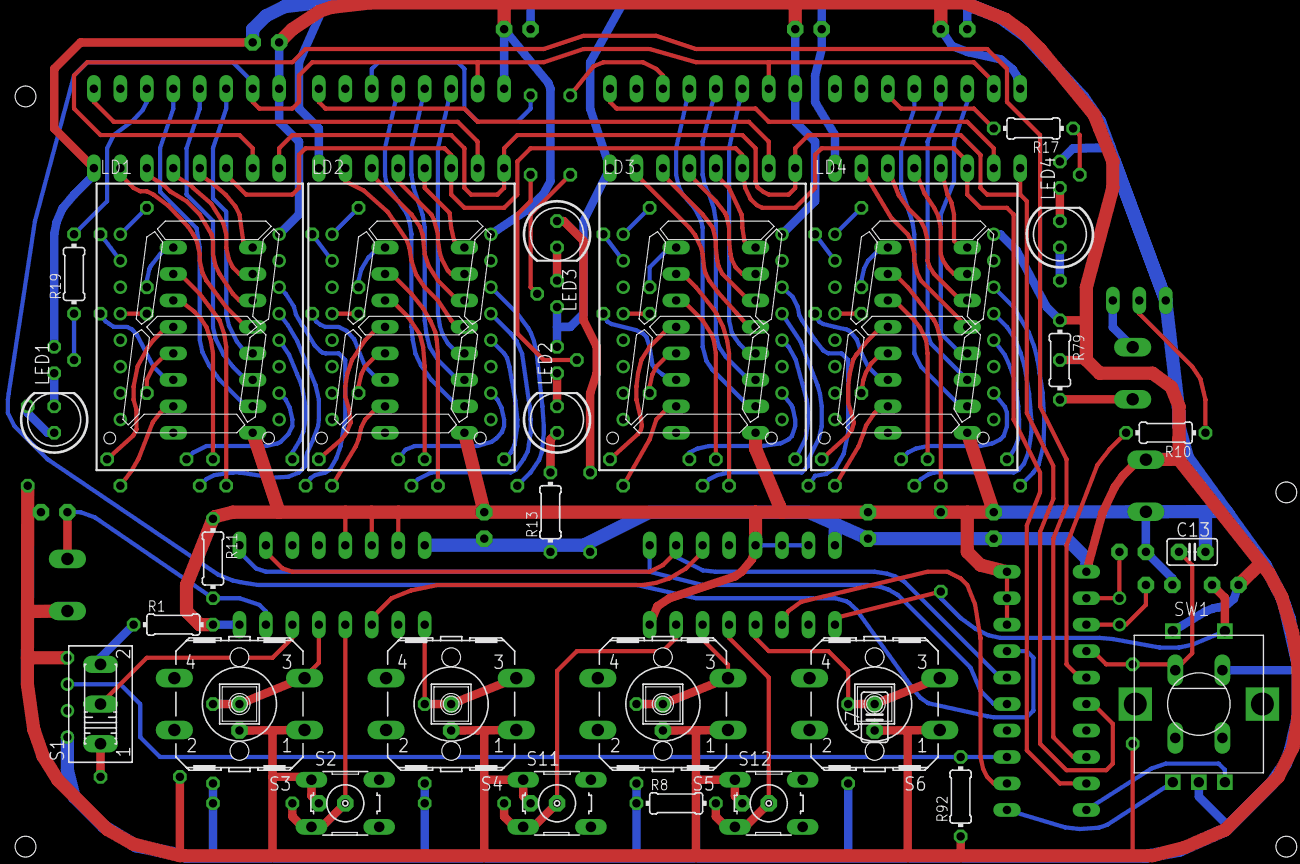
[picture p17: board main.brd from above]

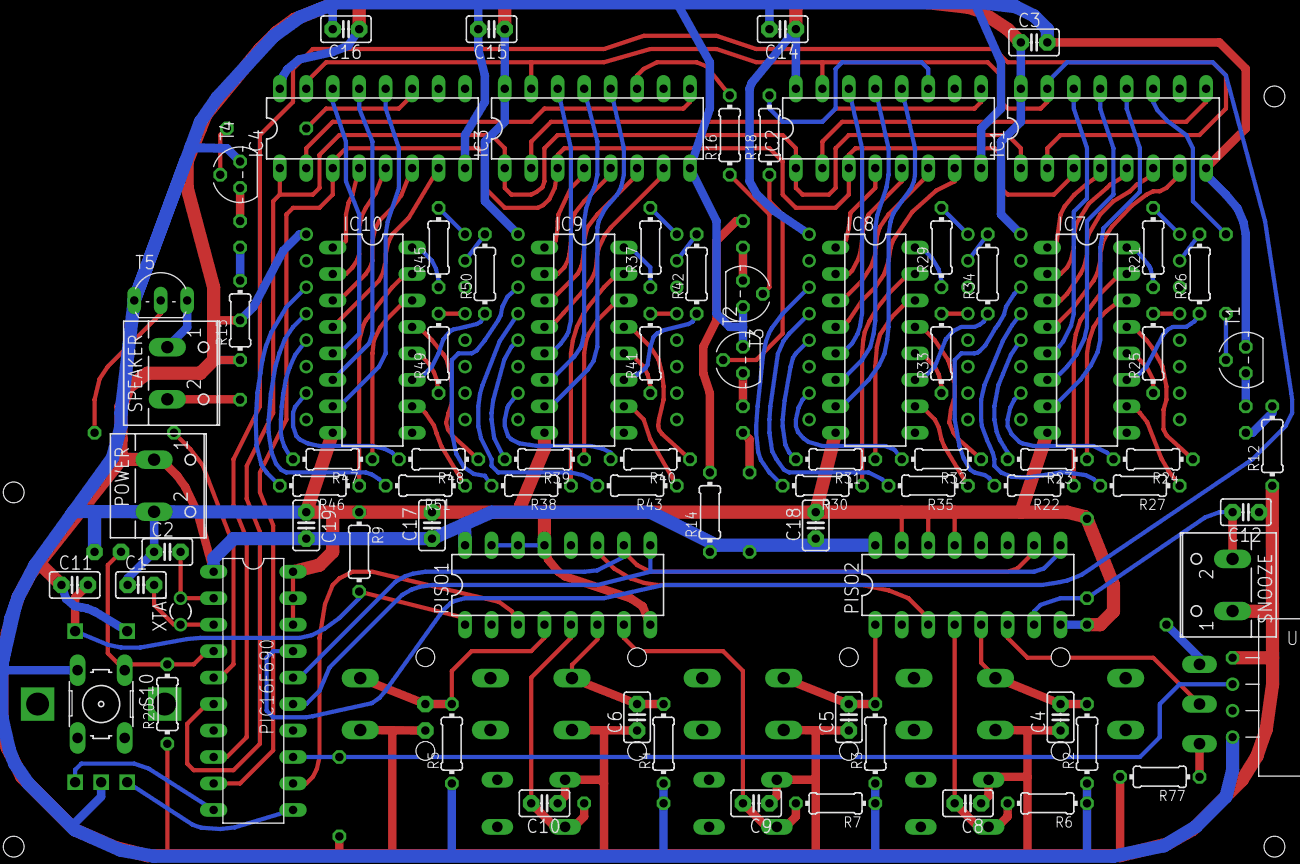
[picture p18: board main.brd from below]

Board: 2 copper layers, 109 parts (81 on the bottom side), 135 nets.

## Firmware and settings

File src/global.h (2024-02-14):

#ifndef GLOBAL_H
#define	GLOBAL_H

#define _XTAL_FREQ          8000000

#define LOOP_INTERVAL_MS    10   // 10 milliseconds
#define SENSOR_INTERVAL_MS  3000 // 3 seconds
#define INIT_DELAY_MS       2000 // 1 sec delay until main loop starts
#define ERROR_DELAY_MS      2000 // 2 sec pause to display an error

#define MAX_SNOOZE          60
#define MIN_SNOOZE          1
#define DEFAULT_SNOOZE      10

#define MAX_VOLUME          100
#define MIN_VOLUME          0
#define DEFAULT_VOLUME      50

//#define MAX_BRIGHTNESS      100
//#define MIN_BRIGHTNESS      1
//#define DEFAULT_BRIGHTNESS  50

#define ERROR_SENSOR        (1 << 0)

#include "sensor.h"

typedef struct
{
    // Sensor
    struct sensor_data_s sensor_data;
    // Message
    uint32_t message;
    // Timer
    volatile uint32_t timer_us;
    volatile uint32_t timer_ms;
    volatile uint8_t timer_q : 2;
    volatile uint8_t sec_tic_calls : 5;
    volatile uint8_t t0_expire : 1;
    // State
    uint8_t current_state;
    // Alarm
    uint8_t snooze_minutes;
    uint8_t alarm_song_id;
    uint8_t alarm_timer_on : 1;
    uint8_t alarm_snoozing : 1;
    uint8_t alarming : 1;
    // Sensor
    uint8_t sensor_mode : 2; // (C)elsius, (F)ahrenheit, (H)umidity, (L)ux
    // Audio
    uint8_t audio_test : 1;
    uint8_t audio_random : 1;
    uint8_t audio_playing : 1;
    uint8_t audio_volume;
    // Brightness
    //uint8_t user_brightness;
    //uint8_t auto_brightness : 1;
    // Timer settings
    uint8_t time_set_minutes : 1;
    uint8_t clock_ticking : 1;
    // Misc
    uint8_t error : 6;
} Global_t;

extern Global_t Global;

#endif	/* GLOBAL_H */

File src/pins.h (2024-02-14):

#ifndef PINS_H
#define	PINS_H

#include "macro.h"

#define AUDIO_PIN    PWM_A // pin 5
#define DHT11_PIN    B,4 // pin 13
#define SIPO_OE      A,2 // pin 17

#define SIPO_LAT_PIN C,4 // pin 6
#define SIPO_CLK_PIN C,7 // pin 9
#define SIPO_DAT_PIN C,6 // pin 8

#define PISO_LAT_PIN C,1 // pin 15
#define PISO_CLK_PIN C,0 // pin 16
#define PISO_DAT_PIN B,5 // pin 12

#define ENC_PIN_A    B,6 // pin 11
#define ENC_PIN_B    B,7 // pin 10
#define ENC_PIN_BOTH (PORT_NTH_BIT(ENC_PIN_A) | PORT_NTH_BIT(ENC_PIN_B))

#endif	/* PINS_H */

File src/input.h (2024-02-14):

#ifndef INPUT_H
#define INPUT_H

// All buttons are active high, with pull-down resistors to hold them low
// Push = When hit once, triggers a function at a rising edge signal
// Hold = When held down, selects and displays a specific program state
// Switch = Sets program options depending on logic high or low
// Virtual buttons are used for input events generated by the code
enum BUTTON_BIT
{
    // PISO 1
    BTN_ALARM_TIMER_ON = 0, // PI1 (Switch)
    BTN_ENCODER     = 1,  // PI2 (Push)
    BTN_ALARM_SET   = 2,  // PI3 (Hold/Push)
    BTN_TIME_SET    = 3,  // PI4 (Hold)
    BTN_SEC_SET     = 4,  // PI5 (Hold)
    BTN_SENSOR      = 5,  // PI6 (Hold)
    
    // PISO 2
    BTN_VOLUME_SET  = 8,  // PI1 (Hold)
    BTN_TUNE_SET    = 9,  // PI2 (Hold)
    BTN_BRIGHT_SET  = 10, // PI3 (Hold)
    BTN_SNOOZE      = 11, // PI4 (Hold/Push)
    
    // virtual buttons
    BTN_ENCODER_CW  = 13,
    BTN_ENCODER_CCW = 14,
    BTN_NONE        = 15
};

// Buttons that cannot be pushed simultaneously
#define BTN_HOLD_MASK ( \
    (1<<BTN_ALARM_SET)  | \
    (1<<BTN_TIME_SET)   | \
    (1<<BTN_SEC_SET)    | \
    (1<<BTN_SENSOR)     | \
    (1<<BTN_VOLUME_SET) | \
    (1<<BTN_SNOOZE))

    //(1<<BTN_TUNE_SET)   | \
    //(1<<BTN_BRIGHT_SET) | \

#define ENCODER_CCW 0
#define ENCODER_CW  1
#define ENC_MAX_EVENTS 15

#endif/* INPUT_H */
